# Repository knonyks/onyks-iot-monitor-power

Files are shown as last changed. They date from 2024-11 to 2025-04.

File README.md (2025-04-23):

## ESP32 power meter

Based on:

* ACS712 - 30A
* 2ma - 2ma voltage measuring transformer
* ADS1115 - I2C ADC 16bit

Programer:

* [ESP-prog](https://docs.espressif.com/projects/esp-iot-solution/en/latest/hw-reference/ESP-Prog_guide.html)
* [voltage module schematic](https://diyprojectslab.com/zmpt101b-voltage-sensor-module-with-arduino/)

Power suply:
	
* [220V-5V_1000mA/2000mA](https://pl.aliexpress.com/item/1005005029575292.html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)

Connector:
	
* [Screw_connectorm_8x8_M3](https://pl.aliexpress.com/item/1005007060857910.html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)

### TO DO:

- [x] Add prog connector and essentials for esp32
- [x] Add pads for Isens
- [x] Add voltage sensor
- [x] Change footpirnts
- [ ] Test ad-dc converter
- [x] Add relay
- [x] Add extra outputs (5V, sig, GND)

### PCB V1 (not for production):

* [schematic](img/V1/schematic_v1.pdf)
* [bom](fab/V1/ibom.html)
* PCB

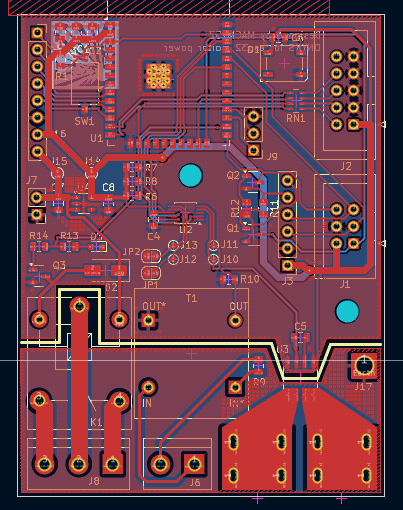
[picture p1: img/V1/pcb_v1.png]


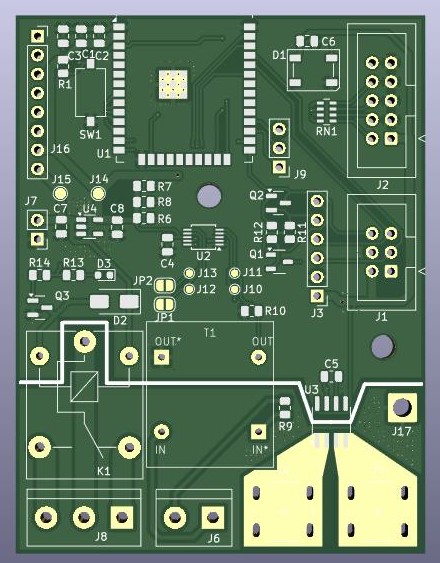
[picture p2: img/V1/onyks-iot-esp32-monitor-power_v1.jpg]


---

Author: Maciej Załęski [macmysz]

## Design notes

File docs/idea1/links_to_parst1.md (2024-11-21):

## Parts from Aliexpress

#### Current measuring modules
* [SCT-013-000 current clamp](https://pl.aliexpress.com/item/32708887594.html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)
* [ACS758 50A module](https://pl.aliexpress.com/item/1005004377998523.html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)
* [ACS712 30A module](https://pl.aliexpress.com/item/32949264545.html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)

#### Voltage measuring modules
* [ZMPT101B transformer module](https://pl.aliexpress.com/item/1005007216813591.html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)
* [ZMPT101B 2mA/2mA transformer](https://pl.aliexpress.com/item/1005004581763279.html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)

#### AC - DC converter
* [5V 10000mA converter](https://pl.aliexpress.com/item/1005005029575292.html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)

#### ADC module
* [ads1115 I2C](https://pl.aliexpress.com/item/4000046686475.html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)

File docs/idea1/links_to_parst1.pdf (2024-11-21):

Parts from Aliexpress

Current measuring modules

- SCT-013-000 current clamp (https://pl.aliexpress.com/item/32708887594.html)
- ACS758 50A module (https://pl.aliexpress.com/item/1005004377998523.html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)
- ACS712 30A module (https://pl.aliexpress.com/item/32949264545.html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)

Voltage measuring modules

- ZMPT101B transformer module (https://pl.aliexpress.com/item/1005007216813591.html)
- ZMPT101B 2mA/2mA transformer (https://pl.aliexpress.com/item/1005004581763279.html)

AC - DC converter

- 5V 10000mA converter (https://pl.aliexpress.com/item/1005005029575292.html)

ADC module

- ads1115 I2C (https://pl.aliexpress.com/item/4000046686475.html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)

1

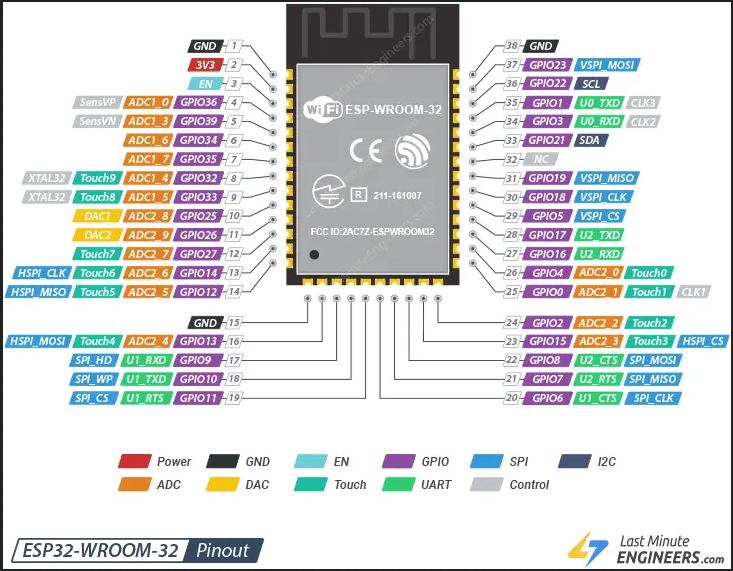
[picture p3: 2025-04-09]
docs/datasheet/Screenshot_20241209_195450.png

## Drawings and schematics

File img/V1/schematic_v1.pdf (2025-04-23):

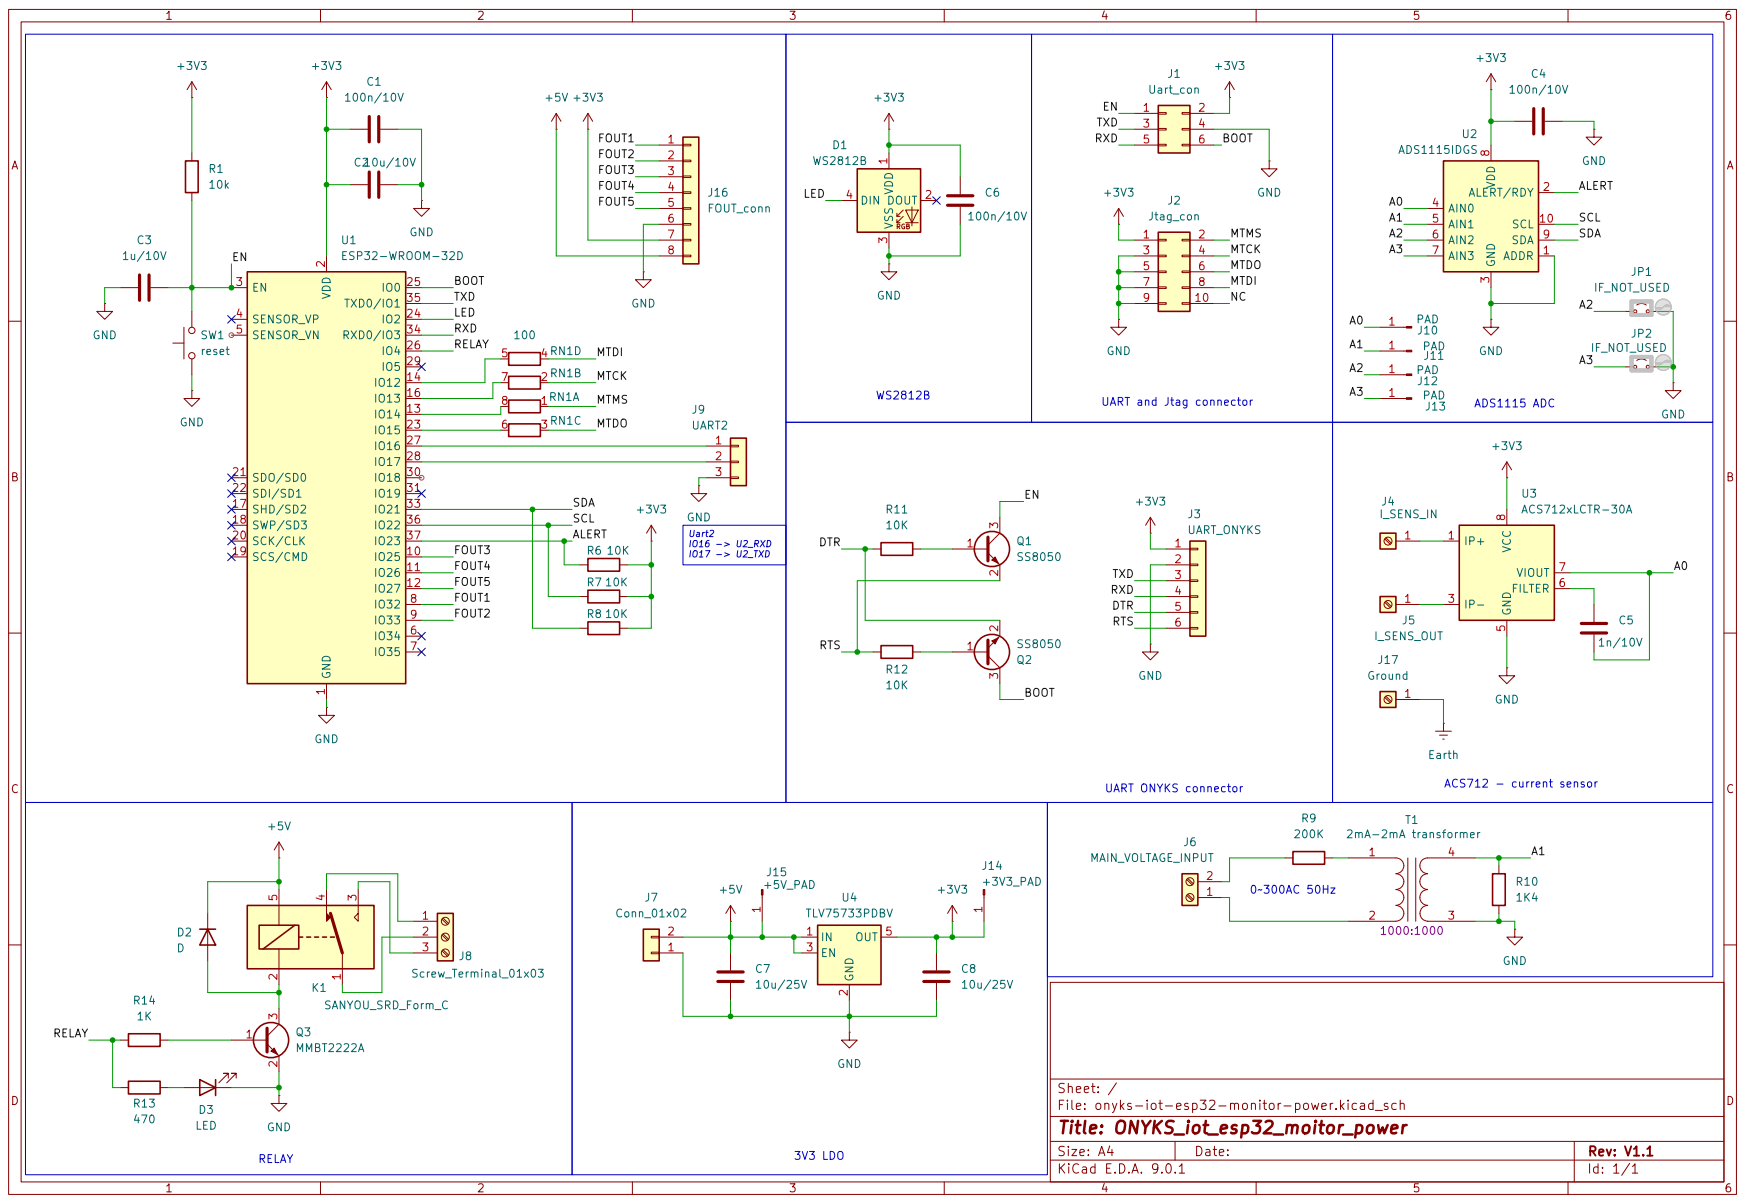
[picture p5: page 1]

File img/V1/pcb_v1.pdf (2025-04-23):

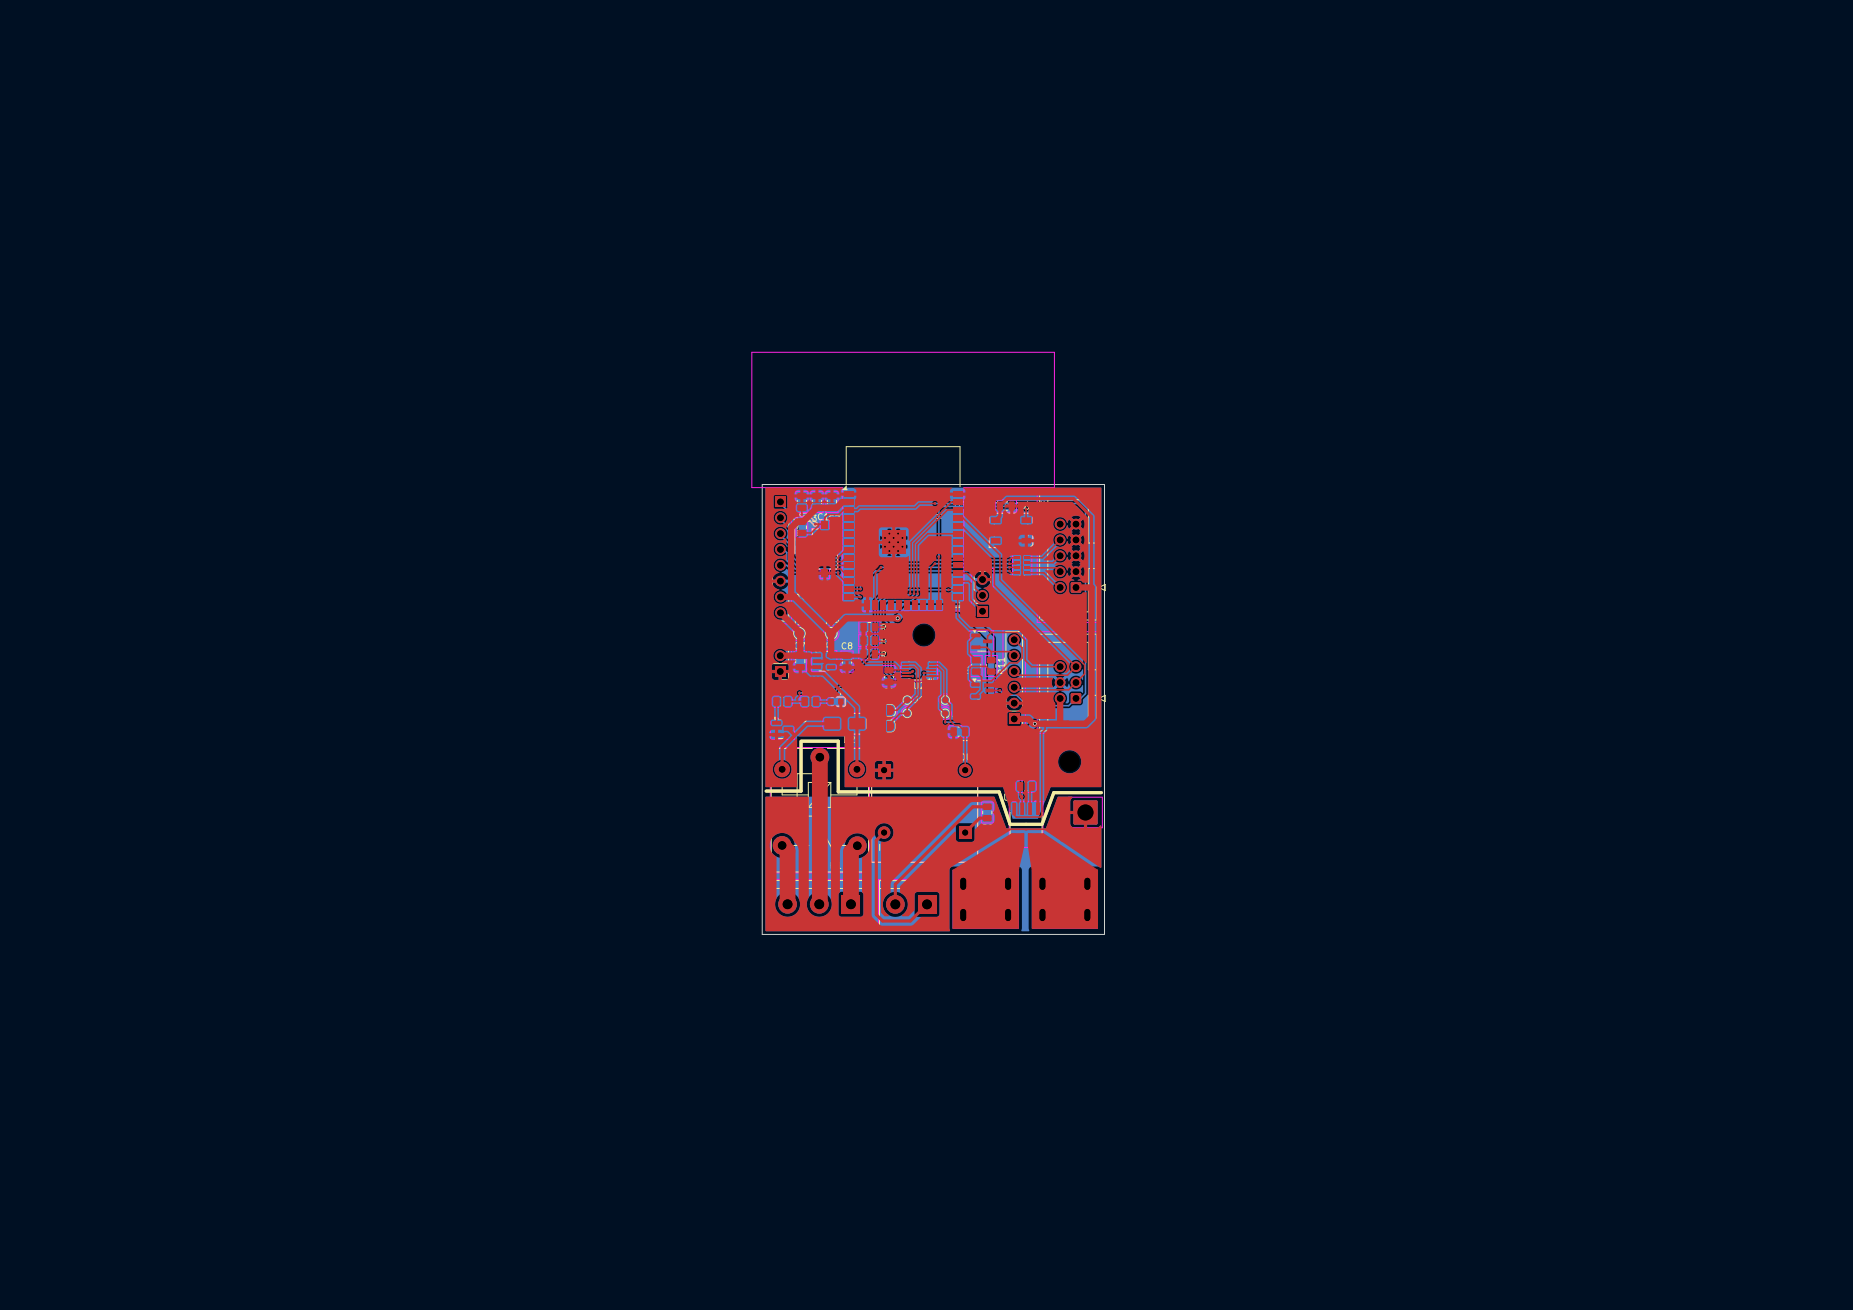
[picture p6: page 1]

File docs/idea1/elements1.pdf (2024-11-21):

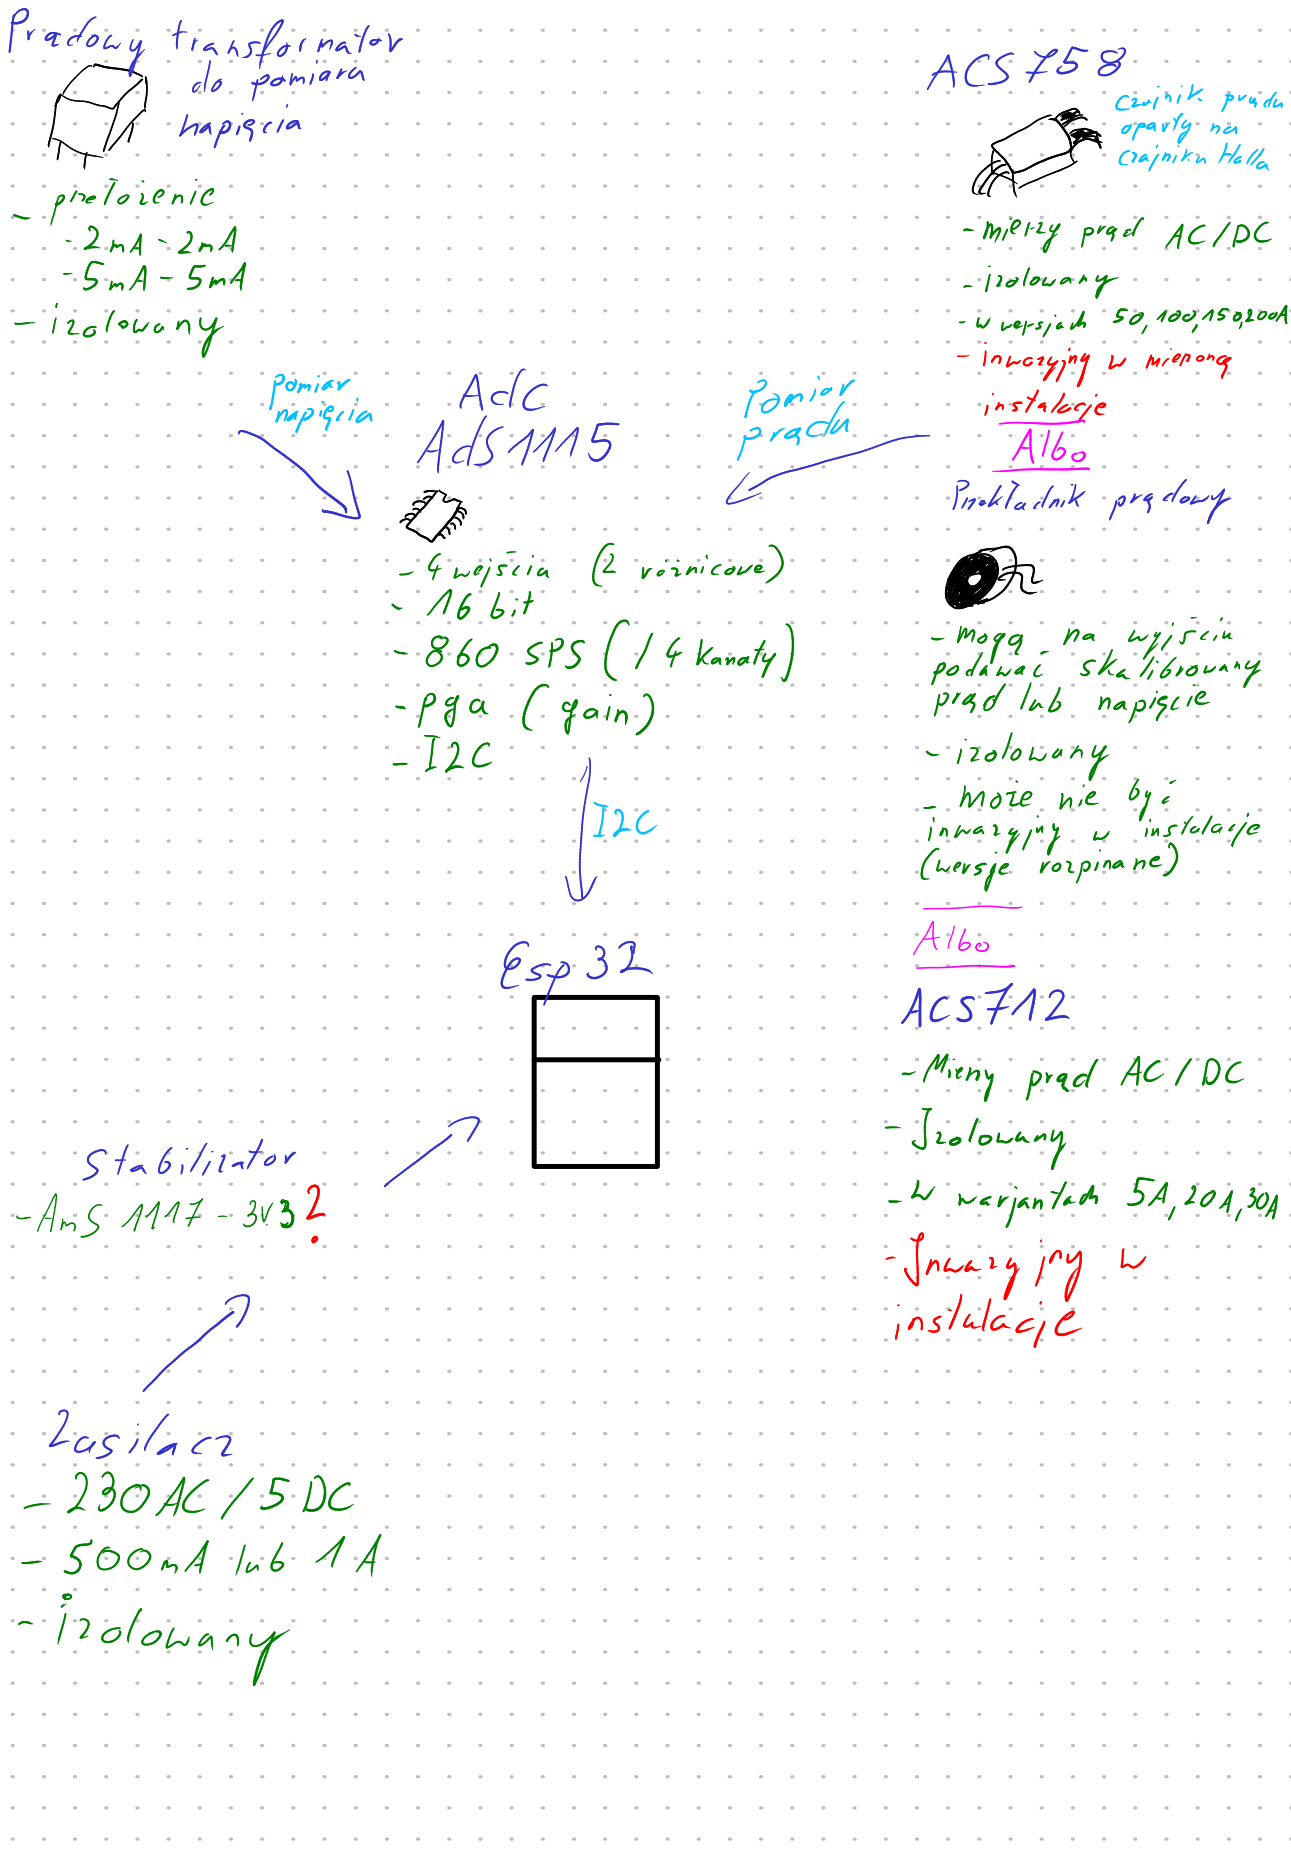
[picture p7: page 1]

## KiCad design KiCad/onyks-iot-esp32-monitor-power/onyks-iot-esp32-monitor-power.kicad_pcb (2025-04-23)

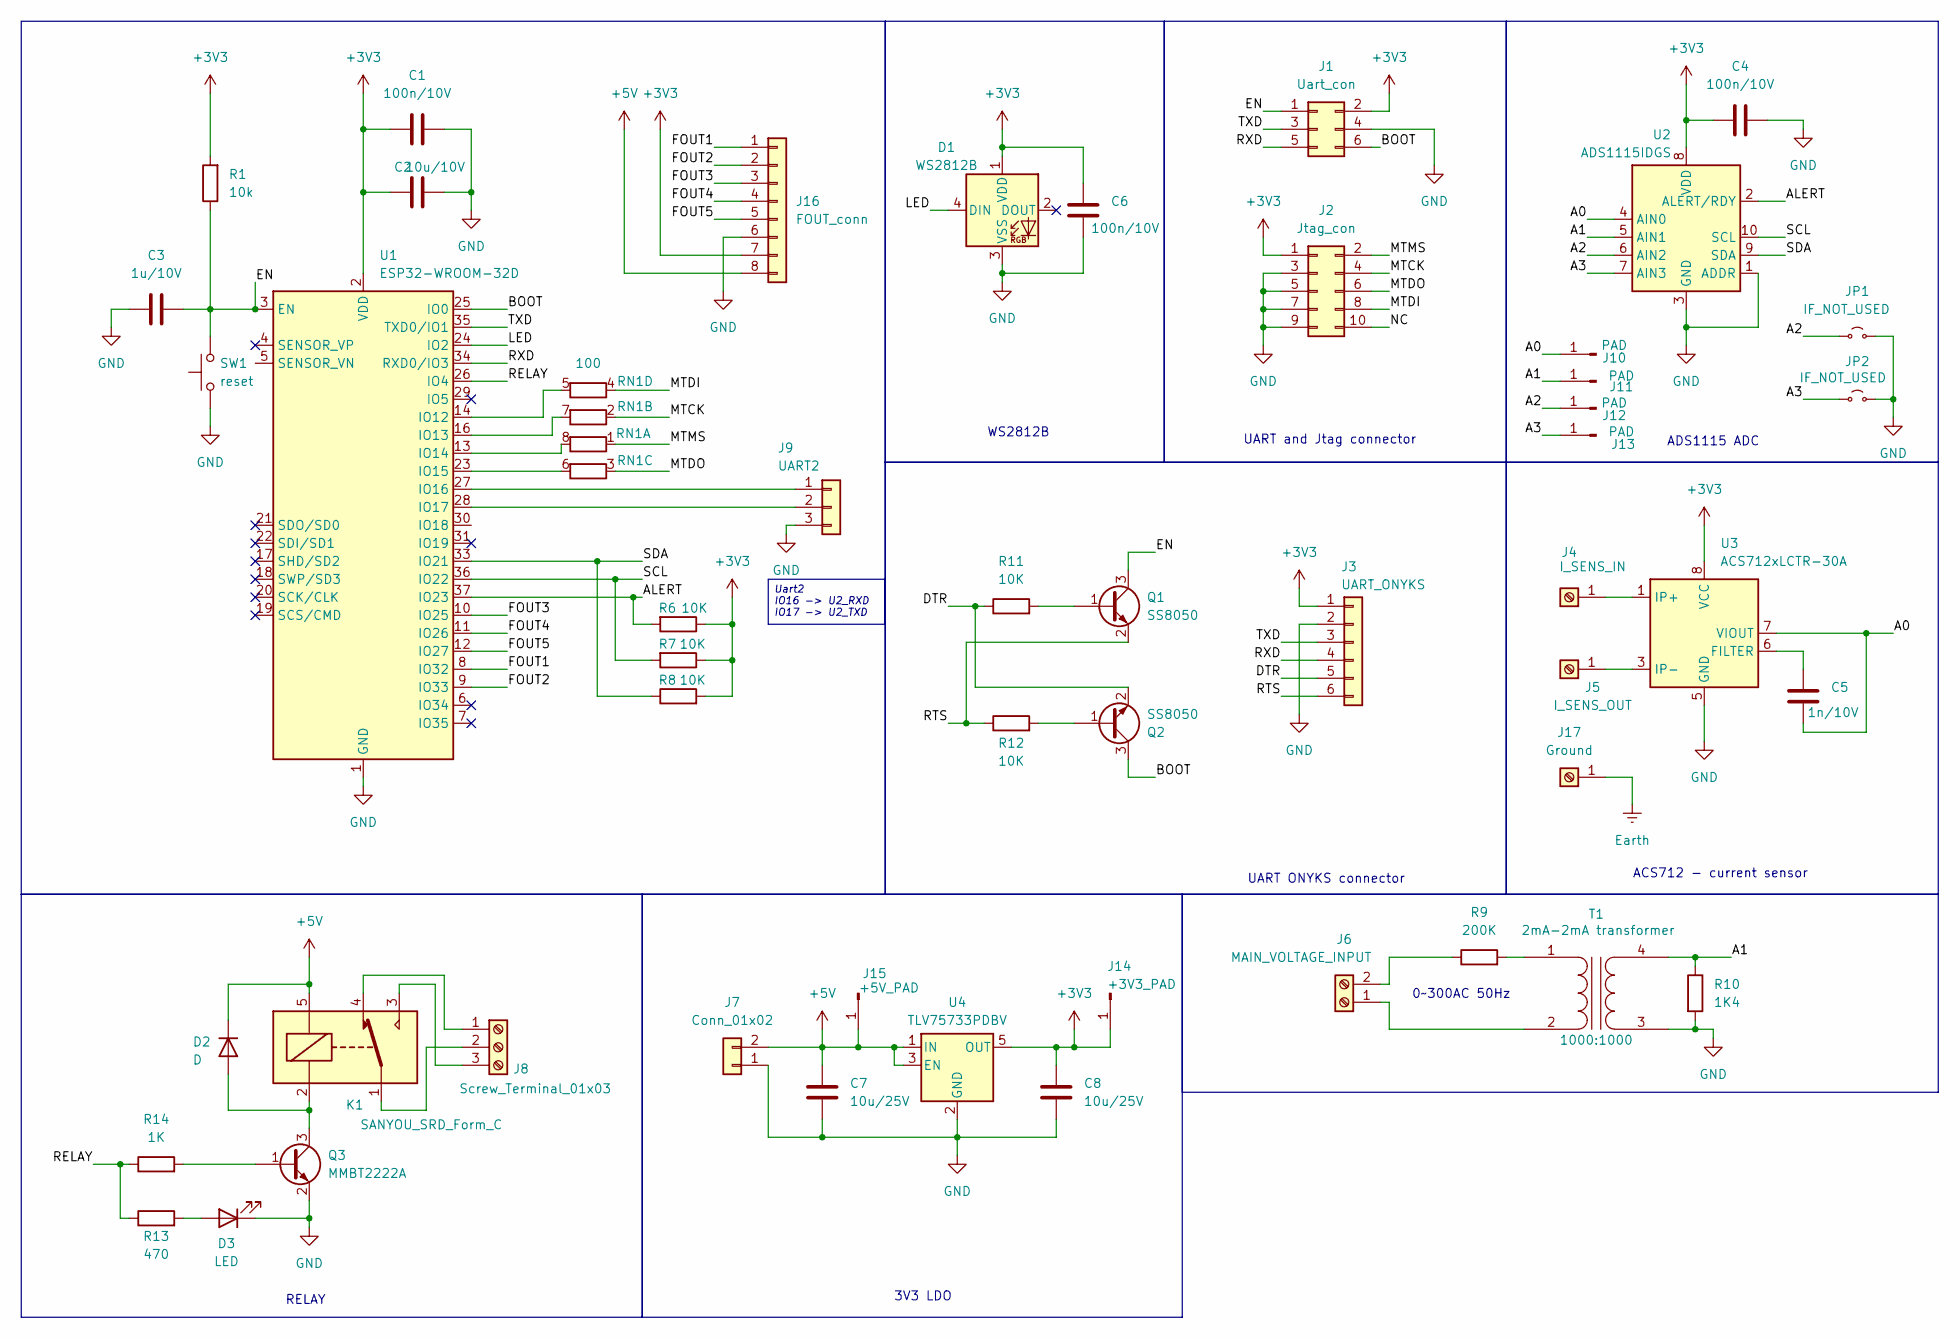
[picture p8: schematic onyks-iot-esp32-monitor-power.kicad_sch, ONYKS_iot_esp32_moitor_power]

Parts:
C1, C4, C6: 100n/10V; C_0805_2012Metric
C2: 10u/10V; C_0805_2012Metric
C3: 1u/10V; C_0805_2012Metric
C5: 1n/10V; C_0805_2012Metric
C7, C8: 10u/25V; C_0805_2012Metric
D1: WS2812B; LED_WS2812B_PLCC4_5.0x5.0mm_P3.2mm
D2: D; D_SMA
D3: LED; LED_0603_1608Metric
J1: Uart_con; IDC-Header_2x03_P2.54mm_Vertical
J2: Jtag_con; IDC-Header_2x05_P2.54mm_Vertical
J3: UART_ONYKS; PinHeader_1x06_P2.54mm_Vertical
J4: I_SENS_IN; Screw Terminal M4 8x8
J5: I_SENS_OUT; Screw Terminal M4 8x8
J6: MAIN_VOLTAGE_INPUT; TerminalBlock_bornier-2_P5.08mm
J7: Conn_01x02; PinHeader_1x02_P2.54mm_Vertical
J8: Screw_Terminal_01x03; TerminalBlock_bornier-3_P5.08mm
J9: UART2; PinHeader_1x03_P2.54mm_Vertical
J10, J11, J12, J13: PAD; TestPoint_Pad_D1.0mm
J14: +3V3_PAD; TestPoint_Pad_D1.5mm
J15: +5V_PAD; TestPoint_Pad_D1.5mm
J16: FOUT_conn; PinSocket_1x08_P2.54mm_Vertical
J17: Ground; SolderWire-2sqmm_1x01_D2mm_OD3.9mm
JP1, JP2: IF_NOT_USED; SolderJumper-2_P1.3mm_Open_RoundedPad1.0x1.5mm
K1: SANYOU_SRD_Form_C; Relay_SPDT_SANYOU_SRD_Series_Form_C
Q1: SS8050; SOT-23-3
Q2: SS8050; SOT-23
Q3: MMBT2222A; SOT-23
R1: 10k; R_0805_2012Metric
R6, R7, R8, R11, R12: 10K; R_0805_2012Metric
R9: 200K; R_0805_2012Metric
R10: 1K4; R_0805_2012Metric
R13: 470; R_0805_2012Metric
R14: 1K; R_0805_2012Metric
RN1: 100; R_Array_Concave_4x0603
SW1: reset; SW_Tactile_SPST_NO_Straight_CK_PTS636Sx25SMTRLFS
T1: 2mA-2mA transformer; ZMPT101B
U1: ESP32-WROOM-32D
U2: ADS1115IDGS; TSSOP-10_3x3mm_P0.5mm
U3: ACS712xLCTR-30A; SOIC-8_3.9x4.9mm_P1.27mm
U4: TLV75733PDBV; SOT-23-5

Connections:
+3V3: C1.2, C2.1, C4.1, C6.1, C8.1, D1.1 (VDD), J1.2, J2.1, J3.1, J14.1, J16.7, R1.2, R6.1, R7.1, R8.2, U1.2 (VDD), U2.8 (VDD), U3.8 (VCC), U4.5 (OUT)
+5V: C7.1, D2.1 (K), J7.2, J15.1, J16.8, K1.5, U4.1 (IN), U4.3 (EN)
/A0: C5.1, J10.1, U2.4 (AIN0), U3.7 (VIOUT)
/A1: J11.1, R10.1, T1.4 (SB), U2.5 (AIN1)
/A2: J12.1, JP1.1 (A), U2.6 (AIN2)
/A3: J13.1, JP2.1 (A), U2.7 (AIN3)
/ALERT: R6.2, U1.37 (IO23), U2.2 (ALERT/RDY)
/BOOT: J1.6, Q2.3 (C), U1.25 (IO0)
/DTR: J3.5, Q2.2 (E), R11.1
/EN: C3.2, J1.1, Q1.3 (C), R1.1, SW1.2, U1.3 (EN)
/FOUT1: J16.1, U1.8 (IO32)
/FOUT2: J16.2, U1.9 (IO33)
/FOUT3: J16.3, U1.10 (IO25)
/FOUT4: J16.4, U1.11 (IO26)
/FOUT5: J16.5, U1.12 (IO27)
/LED: D1.4 (DIN), U1.24 (IO2)
/MTCK: J2.4, RN1.2 (R2.1)
/MTDI: J2.8, RN1.4 (R4.1)
/MTDO: J2.6, RN1.3 (R3.1)
/MTMS: J2.2, RN1.1 (R1.1)
/NC: J2.10
/RELAY: R13.1, R14.1, U1.26 (IO4)
/RTS: J3.6, Q1.2 (E), R12.1
/RXD: J1.5, J3.4, U1.34 (RXD0/IO3)
/TXD: J1.3, J3.3, U1.35 (TXD0/IO1)
Earth: J17.1
GND: C1.1, C2.2, C3.1, C4.2, C6.2, C7.2, C8.2, D1.3 (VSS), D3.1 (K), J1.4, J2.3, J2.5, J2.7, J2.9, J3.2, J7.1, J9.3, J16.6, JP1.2 (B), JP2.2 (B), Q3.2 (E), R10.2, SW1.1, T1.3 (SA), U1.1 (GND), U1.15 (GND), U1.38 (GND), U1.39 (GND), U2.1 (ADDR), U2.3 (GND), U3.5 (GND), U4.2 (GND)
unnamed: D2.2 (A), K1.2, Q3.3 (C)
unnamed: D3.2 (A), R13.2
unnamed: J4.1, U3.1 (IP+), U3.2 (IP+)
unnamed: J5.1, U3.3 (IP-), U3.4 (IP-)
unnamed: J6.1, T1.2 (AB)
unnamed: J6.2, R9.1
unnamed: J8.1, K1.4
unnamed: J8.2, K1.1
unnamed: J8.3, K1.3
unnamed: J9.1, U1.27 (IO16)
unnamed: J9.2, U1.28 (IO17)
unnamed: Q1.1 (B), R11.2
unnamed: Q2.1 (B), R12.2
unnamed: Q3.1 (B), R14.2
unnamed: RN1.8 (R1.2), U1.13 (IO14)
unnamed: RN1.7 (R2.2), U1.16 (IO13)
unnamed: RN1.6 (R3.2), U1.23 (IO15)
unnamed: RN1.5 (R4.2), U1.14 (IO12)
unnamed: R9.2, T1.1 (AA)
unnamed: C5.2, U3.6 (FILTER)
SCL: R7.2, U1.36 (IO22), U2.10 (SCL)
SDA: R8.1, U1.33 (IO21), U2.9 (SDA)

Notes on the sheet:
ACS712 - current sensor
UART and Jtag connector
UART ONYKS connector
ADS1115 ADC
WS2812B
0~300AC 50Hz
3V3 LDO
RELAY
Uart2 IO16 -> U2_RXD IO17 -> U2_TXD

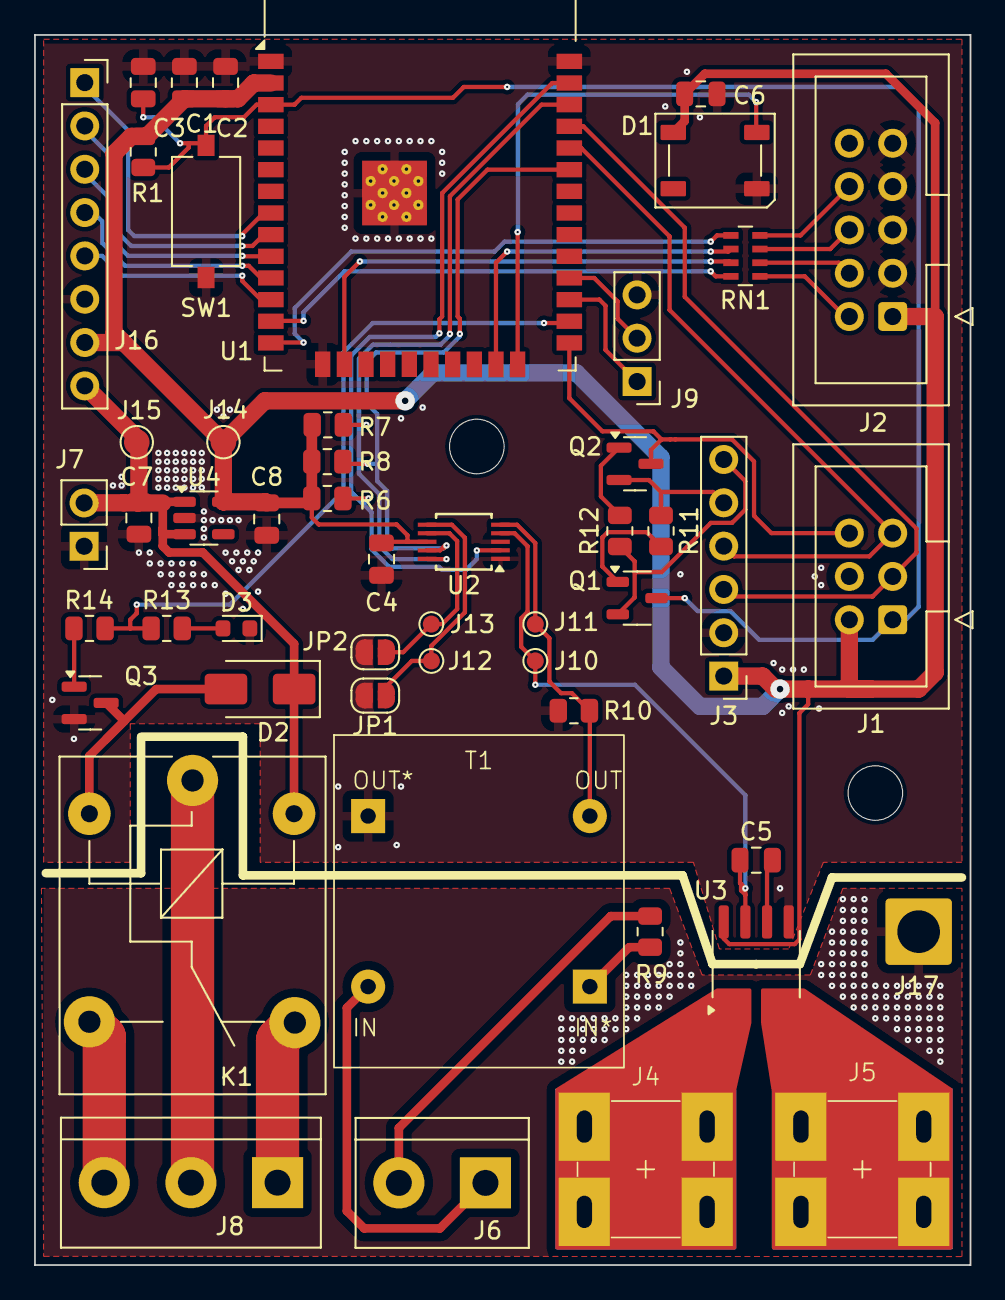
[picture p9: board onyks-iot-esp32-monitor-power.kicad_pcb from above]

Board: 2 copper layers, 54.9 x 72.1 mm, 51 parts (0 on the bottom side), 47 nets.

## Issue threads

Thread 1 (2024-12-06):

A controllabe outlet

przemech, 2024-12-06:
If the project will be built into a power strip, then I thought why not to control the outlets?
But I think we don't need to control them all, but maybe just one?

This is just an idea, not to be done yet. Perhaps this is already over-engineering?

macmysz, 2024-12-08:
It's no problem at all to add relay controling outlets. For more than one relay i could add connetors with power and signal. They could be used for anything else. I have quite a lot free pins at the moment.

macmysz, 2024-12-09:
I added relay and extra free gpio. If you have any suggestions to change J16 symbol.

przemech, 2024-12-09:
I think you could use just a connector like e.g.:
`Conn_01x07
Generic connector, single row, 01x07, script generated (kicad-library-utils/schlib/autogen/connector/)`

macmysz, 2024-12-09:
I will change it. I still think how to place components to make pcb smaller. To next Monday i will try to finish it.

macmysz, 2024-12-15:
i added relay and changed connector to 01x08

Closed 2024-12-15.

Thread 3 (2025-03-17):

Uwagi - checklist

przemech, 2025-03-17:
### Uniwersalne uwagi - checklist:

Przy następnym PCB zastosuje:

- [ ] [Hierarchiczna struktura schematu](https://docs.kicad.org/master/en/eeschema/eeschema.html#hierarchical-schematics)
- [ ] Global Label -> Hierarchical Label (między schematami)
- [ ] Obudowy SMD 0603 (ew. dla kondesnatorów o dużych pojemnościach 0805)

Do poprawy:
- [x] Global Label -> Net Label (lokalne)
- [x] No Connect Flags dla niepodłączoncych pinów
- [x] Czytanie schematów od lewej do prawej -> np. zasilanie po lewej i odbiorca po prawej
- [x] Napięcia przy kondensatorach np. 10u -> 10n/10V
- [ ] Przy złączu zasilania opis zakresu napięcia i maksymalny prąd

**nie dotyczy:**
- [ ] Zbyt dokładne wartości elementów (zbyt dokładny szereg)
- [ ] Nazwa modelu cewki do symbolu  jako kolejny field

### Do tego projektu:

Schemat:
- [ ] 4,7k do SPI pull-up
- [x] W przypadku tylko jednego scheetu - tylko Net Labels (aczkolwiek ładnie będzie podzielić na hierarchiczne schematy)
- [x] Napisać informację o uzwojeniach transformatora
- [ ] Może przekaźnik zatrzaskowy (latchowy albo bistabilny) do tego celu - do przemyślenia i uzasadnienia - **1. Takie miałem dostępne po poprzednich projektach (są tanie i dobrze działają) 2. Czemu nie zatrzaskowy - ze względów bezpieczeństwa, by uniknąć sytuacji kiedy esp32 nie działa (z dowolnego powodu), a użądzenia są podłączone nadal do sieci. Nie wiemy co docelowo będzie podłączone do tego użądzenia, a zostawienie ich bez kontroli może być potencjalnie niebezpieczne.**
- [ ] Może dodać bezpiecznik - **myślałem żeby dodać (po stronie AC) do docelowej obudowy, by był prosto dostępny**

Przetestuje jeszcze raz w spice i fizycznie (testowałem to już fizyczne, ale nie zapisałem sobie wyników):
- [ ] Przy ADC do wejść kondesnatory blokujące 10nF
- [ ] Można wrzucić do SPICE tę część z transformatorem - sprawdzić czy nie będzie ucinania sygnału AC
- [ ] Zabezpieczenie - dioda zenera dla A1
- [ ] Sprawdzić jak na A1 z ujemnymi wartościami AC

### PCB:
- [ ] Duże separacje przy części 230V - clearence - odstępy od płaszczyzny masy
- [ ] Szerokie ścieżki zasilania przekładać kilkoma przelotkami (nie tylko jedną) między warstwami płytki
- [ ] Większe przelotki - bo takich nie zrobią - może być 0,3 mm

macmysz, 2025-04-09:
* Może przekaźnik zatrzaskowy (latchowy albo bistabilny) do tego celu - do przemyślenia i uzasadnienia:
 1. Takie miałem dostępne po poprzednich projektach (są tanie i dobrze działają)
 2. Czemu nie zatrzaskowy - ze względów bezpieczeństwa, by uniknąć sytuacji kiedy esp32 nie działa (z dowolnego powodu), a użądzenia są podłączone nadal do sieci. Nie wiemy co docelowo będzie podłączone do tego użądzenia, a zostawienie ich bez kontroli może być potencjalnie niebezpieczne.

* Może dodać bezpiecznik:   myślałem żeby dodać (po stronie AC) do docelowej obudowy, by był prosto dostępny

Jeśli większe zmiany będą potrzebne to mogę dodać te elementy (bezpiecznik, 0603) i po dodatkowym sprawdzeniu pomiaru napięcia i prądu, mogę zaprojektować płytkę od nowa.

macmysz, 2025-04-23:
nowa check lista do v2 pcb
[check list](https://github.com/knonyks/onyks-iot-monitor-power/blob/6741c5c755a12c4f55b8eb0406151acc68169b57/docs/V2/check_list.md)
czy dodać coś jeszcze?

przemech, 2025-04-23:
Taką checklistą chyba łatwiej będzie zarządzać w issue, łatwo się do czegokolwiek odnieść

macmysz, 2025-04-23:
## Things to repair:

#### Testing

- [ ] test measuring voltage with transformer
        - [ ] add 10nF separating cap at ADC inputs
        - [ ] add zener diode for protection at ADC inputs
        - [ ] test with spice (and make note)
        - [ ] check if negative voltage doesn't get clipped
        - [ ] build and test the circuit (and make note)

- [ ] test measuring current with ACS712
        - [ ] add 10nF separating cap at ADC inputs
        - [ ] add zener diode for protection at ADC inputs
        - [ ] test with spice **if model is avalible**(and make note)
        - [ ] check if negative voltage doesn't get clipped
        - [ ] build and test the circuit (and make note)

- [ ] preper unused ADC pins for use
        - [ ] add optional voltage divider
        - [ ] add 10nF separating capacitor at ADC inputs
        - [ ] add zener diode for protection at ADC inputs
        - [ ] optional: add some extra connector

#### Schematic

- [ ] change elements size (from 0805 to 0603)
- [ ] calculate max ampreg and power
- [ ] add 4,7k pullup for SPI
- [ ] add smd fuse for 5V
- [ ] add replaceble fuse for 230V relay (high side)

#### PCB

- [ ] add mounting holes
- [ ] import via and track size from JLCPCB
- [ ] make wider gap betwen Low and High side (clerance)(mabe cuts?)
- [ ] add text with voltage and max amperage near power connector
- [ ] add multiple vias to wider tracks

Closed 2025-04-09.

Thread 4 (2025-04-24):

Review od @KacperZezulinski

przemech, 2025-04-24:
od @KacperZezulinski

- [ ] napięcie na T1 - czy nie będzie miało ujemnych wartości? można dodać diodę zabezpieczającą by nie zeszło poniżej 0V
- [ ] dla estetyki zrobić by linia masy nie przecinała (opcjonalnie), dla np. J3:

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

- [ ] pull up SPI raczej 4,7k zamiast 10k - dla większych prędkości
- [ ] poukładać przy przycisku reset, coś w tym stylu:

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

- [ ] C2 i C1 zamienić miejscami - pokazanie, że kondensator o mniejszej pojemności jest bliżej MCU

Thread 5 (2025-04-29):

pomiary adc

macmysz, 2025-04-29:
rzeczy które na razie wynikły z symulowania i testowania pomiaru prądu zmiennego:

* ADS1115 nie pracuje w zakresie +-. Napięcie na wejściach adc muszą się mieścić w GND - 0.3V do VDD + 0.3V. Trzeba będzie przez to przesunąć napięcie z wyjścia transformatora o VDD/2
* Rezystor R1 ograniczający prąd po pierwotnej stronie transformatora będzie mógł wydzielić na sobie ponad 500mW. Powinien być na pewno większy niż teraz zastosowany
* Dopracowania wymaga zabezpieczenie z diod zenera. Nie jestem narazie co do niego pewien.

---

* Zamiast dwóch diod zenera lepiej może się sprawdzić dwukierunkowa dioda TVS.
* Można zmniejszyć wartość R3 lub usunąć go wcale po dobraniu odpowiedniej diody TVS. Chwilowo R3 służył jako ogranicznik prądu, by przez diody zenera nie popłynoł za duży prąd.
* Sygnał wyjściowy przy 325Vpp na wejsciu, miesci się w zakresie +-500mV. Teraz trzeba odpowiednio dobrać zakres pracy ADS który ma PGA(programowalny wzmacniacz operacyjny) i sprawdzić czy różne kanały mogą mieć różne wzmocnienie?
* Źródło V2 dające VDD/2 jako składową stałą, trzeba zastąpić stabilizatorem albo źródłem odniesienia.
* Może się okazać że trzeba będzie zasilać ADC z 5V a nie z 3V3 z powodu czujnika prądu, który może nie działać poprawnie na 3V3. Do sprawdzenia

Closed 2025-04-30.

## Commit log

2024-11-21 add KiCad project
    [onyks-iot-esp32-monitor-power.kicad_pcb, onyks-iot-esp32-monitor-power.kicad_sch]
2024-12-02 update schemati
    [onyks-iot-esp32-monitor-power.kicad_sch]
2024-12-02 Add ACS712 and ADS1115
    [onyks-iot-esp32-monitor-power.kicad_sch]
2024-12-02 edit schemat
    [onyks-iot-esp32-monitor-power.kicad_sch]
2024-12-08 scheme v1; Add fotprints
    [onyks-iot-esp32-monitor-power.kicad_pcb, onyks-iot-esp32-monitor-power.kicad_sch]
2024-12-08 Add relay to sheme (not ended)
    [onyks-iot-esp32-monitor-power.kicad_pcb, onyks-iot-esp32-monitor-power.kicad_sch]
2024-12-09 Add relay and 5x extra free GPIO; sheme V1.1
    [onyks-iot-esp32-monitor-power.kicad_pcb, onyks-iot-esp32-monitor-power.kicad_sch]
2024-12-09 start editing pcb
    [onyks-iot-esp32-monitor-power.kicad_pcb, onyks-iot-esp32-monitor-power.kicad_sch]
2024-12-13 edit pcb
    [onyks-iot-esp32-monitor-power.kicad_pcb, onyks-iot-esp32-monitor-power.kicad_sch]
2024-12-15 pcb finished
    [onyks-iot-esp32-monitor-power.kicad_pcb]
2024-12-16 add Logo
    [onyks-iot-esp32-monitor-power.kicad_pcb]
2024-12-18 PCB update
    [onyks-iot-esp32-monitor-power.kicad_pcb]
2024-12-18 update PCB 2
    [onyks-iot-esp32-monitor-power.kicad_pcb]
2025-04-09 schemat errors fix_1
    [onyks-iot-esp32-monitor-power.kicad_sch]
2025-04-23 doc V1
    [onyks-iot-esp32-monitor-power.kicad_pcb]
